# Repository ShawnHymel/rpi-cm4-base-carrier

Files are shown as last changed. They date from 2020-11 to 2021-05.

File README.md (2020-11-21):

# Raspberry Pi Compute Module 4 (CM4) Base Carrier

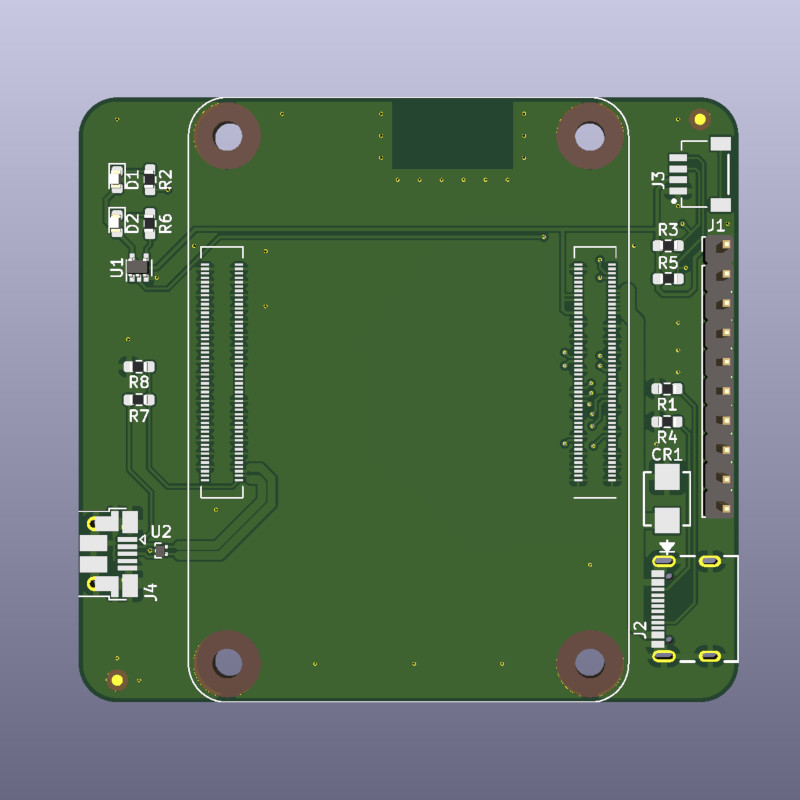
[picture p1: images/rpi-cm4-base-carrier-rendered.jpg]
Rendered example of RPi CM4 Carrier Template PCB


Simple carrier board for the Raspberry Pi Compute Module 4. It provides power to the module through the USB-C connector (power only, no data), USB client mode (host mode is not supported), Qwiic/Stemma connector for I2C lines, SPI, UART, and power/activity LEDs.

Feel free to modify this design for your own application. This PCB is not intended to be an end product but rather a demo to get people started making their own carrier boards for the CM4.

Note that USB traces were calculated for a 2-layer board with a 1.6mm height.

## License

Schematic and PCB layout files are licensed under the [CC BY 4.0](https://creativecommons.org/licenses/by/2.0/) license.

Individual components and footprints found in the CM4IO library are licensed as per the Design Files license found [here](https://datasheets.raspberrypi.org/license.html).

THE DESIGN IS PROVIDED "AS IS" AND THE AUTHOR DISCLAIMS ALL WARRANTIES WITH REGARD TO THIS DESIGN INCLUDING ALL IMPLIED WARRANTIES OF MERCHANTABILITY AND FITNESS. IN NO EVENT SHALL THE AUTHOR BE LIABLE FOR ANY SPECIAL, DIRECT, INDIRECT, OR CONSEQUENTIAL DAMAGES OR ANY DAMAGES WHATSOEVER RESULTING FROM LOSS OF USE, DATA OR PROFITS, WHETHER IN AN ACTION OF CONTRACT, NEGLIGENCE OR OTHER TORTIOUS ACTION, ARISING OUT OF OR IN CONNECTION WITH THE USE OR PERFORMANCE OF THIS DESIGN.

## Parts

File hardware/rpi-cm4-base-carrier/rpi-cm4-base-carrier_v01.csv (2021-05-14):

Reference | Quantity | Value | Footprint | Datasheet | Digi-Key_PN | MPN | Manufacturer | Part Description | AVAILABILITY | DESCRIPTION | MF | MP | PACKAGE | PRICE | STANDARD | Digi-Key_PN (Alt) | Field4 | Field5
CR1 | 1 | SMBJ5.0A-TR | footprints:SMBJ5.0A-TR |  | 497-3144-1-ND | SMBJ5.0A-TR | STMicroelectronics
D1 | 1 | LED Green | LED_SMD:LED_0603_1608Metric | ~ | 160-1478-1-ND | LTST-S270KGKT | Lite-On Inc. | Green 572nm LED Indication - Discrete 2.2V 2-SMD, No Lead
D2 | 1 | LED Red | LED_SMD:LED_0603_1608Metric | ~ | 160-1479-1-ND | LTST-S270KRKT | Lite-On Inc. | Red 620nm LED Indication - Discrete 2.2V 2-SMD, No Lead
J1 | 1 | DNP | Connector_PinHeader_2.54mm:PinHeader_1x10_P2.54mm_Vertical | ~
J2 | 1 | USB4105-GF-A | USB4105-GF-A:GCT_USB4105-GF-A |  | 2073-USB4105-GF-ACT-ND | USB4105-GF-A | GCT |  | Unavailable | USB - C _Type - C_ USB 2.0 Receptacle Connector 24 Position Surface Mount, Right Angle; Through Hole | Global Connector Technology | USB4105 | Package Analog Devices | None
J3 | 1 | SM04B-SRSS-TB(LF)(SN) | SM04B-SRSS-TB_LF__SN_:JST_SM04B-SRSS-TB(LF)(SN) |  | 455-1804-1-ND | SM04B-SRSS-TB(LF)(SN) | JST Sales America Inc. |  |  |  |  |  |  |  | Manufacturer recommendations
J4 | 1 | USB_OTG | CM4IO:USB_Micro-B_EDAC_UCON00686 | ~ | 609-4050-1-ND | 10103594-0001LF | Amphenol ICC (FCI)
JP1 | 1 | SolderJumper_2_Open | Jumper:SolderJumper-2_P1.3mm_Open_RoundedPad1.0x1.5mm | ~
Module1 | 1 | ComputeModule4-CM4 | CM4IO:Raspberry-Pi-4-Compute-Module |  | 2x H11615CT-ND | 2x DF40C-100DS-0.4V | Hirose |  |  |  |  |  |  |  |  | 2x H124602CT-ND | Hirose | 2x DF40C-100DS-0.4V
R1 R4 | 2 | 5.1k | Resistor_SMD:R_0603_1608Metric_Pad0.98x0.95mm_HandSolder | ~ | 311-5.10KHRCT-ND | RC0603FR-075K1L | Yageo
R2 R6 | 2 | 1k | Resistor_SMD:R_0603_1608Metric_Pad0.98x0.95mm_HandSolder | ~ | 311-1.00KHRCT-ND | RC0603FR-071KL | Yageo
R3 R5 | 2 | DNP | Resistor_SMD:R_0603_1608Metric_Pad0.98x0.95mm_HandSolder | ~
R7 R8 | 2 | 2.2K 1% | Resistor_SMD:R_0603_1608Metric_Pad0.98x0.95mm_HandSolder | ~ | 311-2.20KHRCT-ND | RC0603FR-072K2L | Yageo
U1 | 1 | 74LVC1G07SE-7 | Package_TO_SOT_SMD:SOT-353_SC-70-5 | http://www.ti.com/lit/sg/scyt129e/scyt129e.pdf | 74LVC1G07SE-7DICT-ND | 74LVC1G07SE-7 | Diodes Incorporated | Buffer, Non-Inverting 1 Element 1 Bit per Element Open Drain Output SOT-353
U2 | 1 | TPD2EUSB30 | Package_TO_SOT_SMD:Texas_DRT-3 | http://www.ti.com/lit/ds/symlink/tpd2eusb30a.pdf | 296-25509-1-ND | TPD2EUSB30DRTR | Texas Instruments

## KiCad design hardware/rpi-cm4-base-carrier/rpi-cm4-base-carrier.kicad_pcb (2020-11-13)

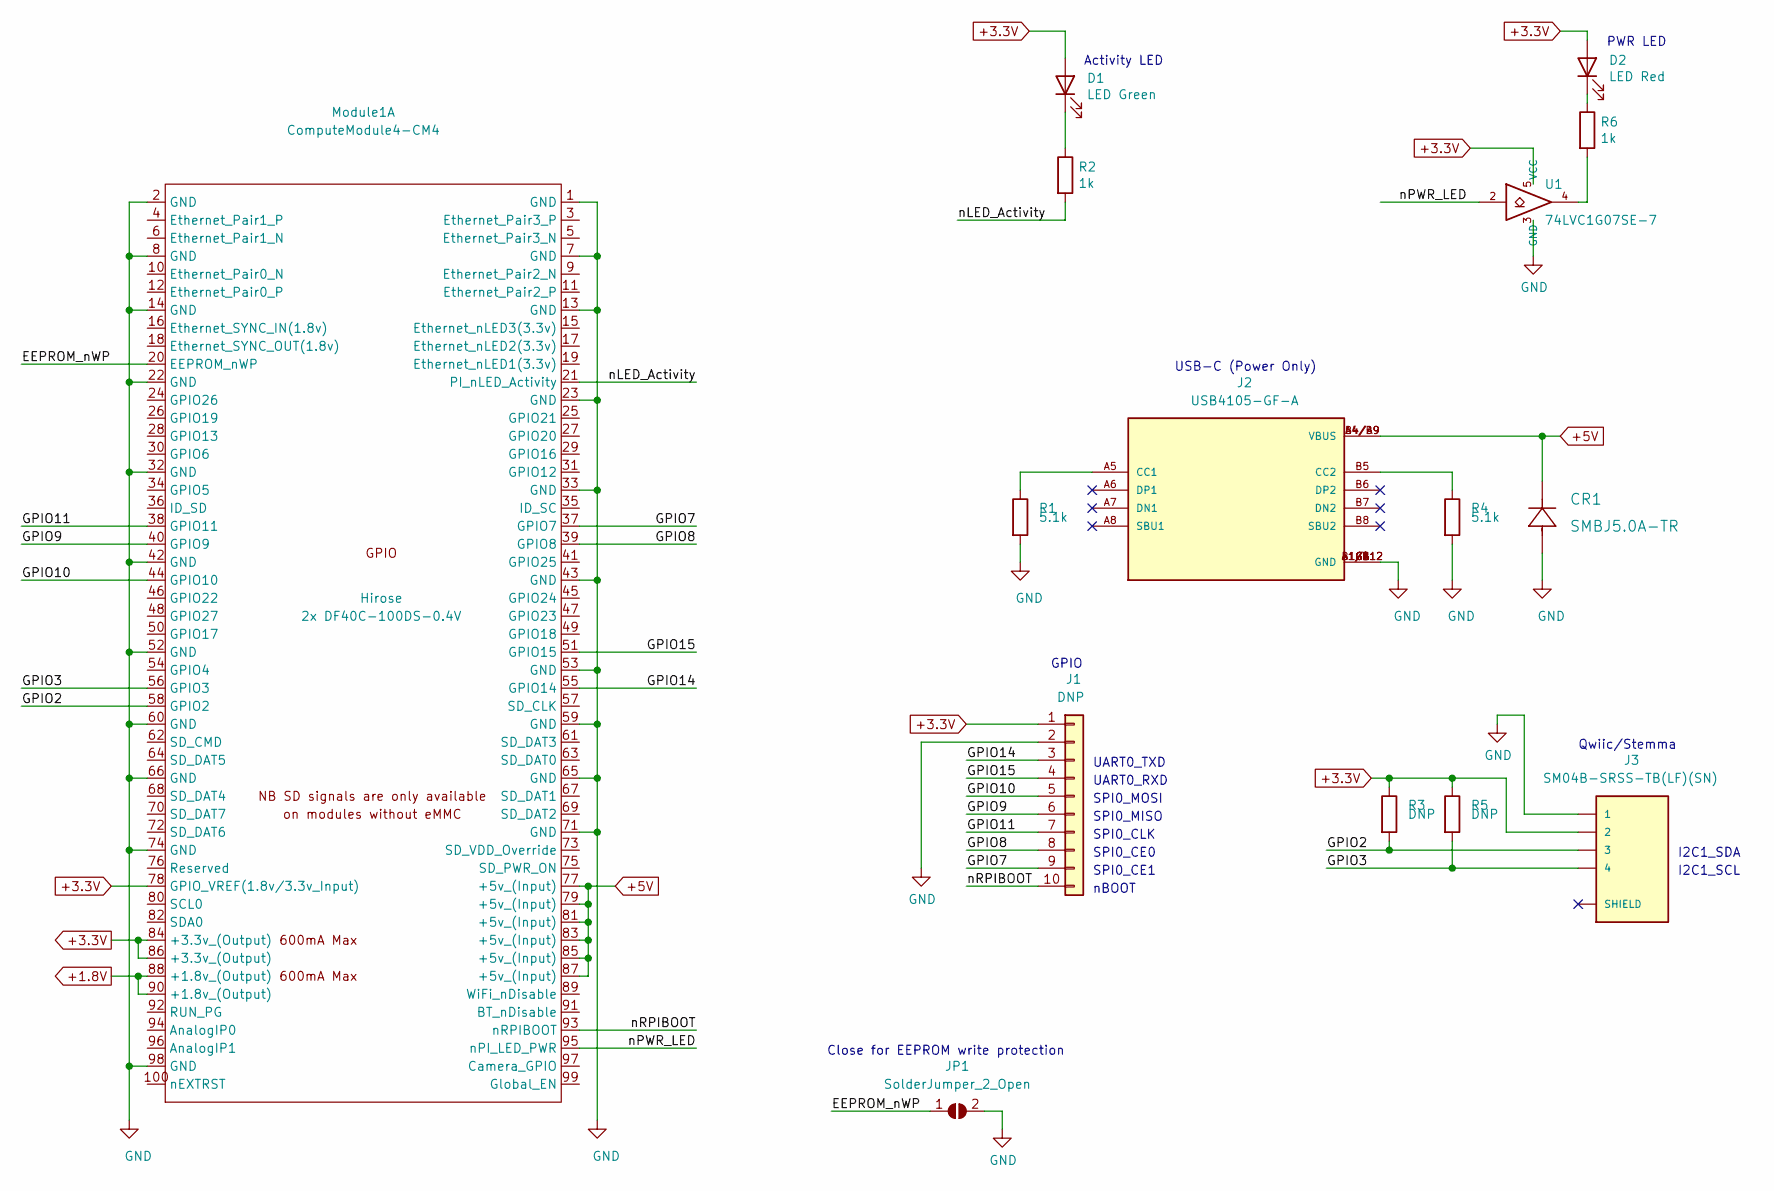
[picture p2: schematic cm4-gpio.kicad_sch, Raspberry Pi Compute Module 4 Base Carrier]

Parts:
CR1: SMBJ5.0A-TR; MPN SMBJ5.0A-TR; Digi-Key_PN 497-3144-1-ND
D1: LED Green; LED_0603_1608Metric; Part Description Green 572nm LED Indication - Discrete 2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; Digi-Key_PN 160-1478-1-ND
D2: LED Red; LED_0603_1608Metric; Part Description Red 620nm LED Indication - Discrete 2.2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; Digi-Key_PN 160-1479-1-ND
J1: DNP; PinHeader_1x10_P2.54mm_Vertical
J2: USB4105-GF-A; GCT_USB4105-GF-A; MPN USB4105-GF-A; Digi-Key_PN 2073-USB4105-GF-ACT-ND
J3: SM04B-SRSS-TB(LF)(SN); JST_SM04B-SRSS-TB(LF)(SN); MPN SM04B-SRSS-TB(LF)(SN); Digi-Key_PN 455-1804-1-ND
JP1: SolderJumper_2_Open; SolderJumper-2_P1.3mm_Open_RoundedPad1.0x1.5mm
Module1: ComputeModule4-CM4; Raspberry-Pi-4-Compute-Module; MPN 2x DF40C-100DS-0.4V; Digi-Key_PN 2x H11615CT-ND
R1, R4: 5.1k; R_0603_1608Metric_Pad0.98x0.95mm_HandSolder; MPN RC0603FR-075K1L; Digi-Key_PN 311-5.10KHRCT-ND
R2, R6: 1k; R_0603_1608Metric_Pad0.98x0.95mm_HandSolder; MPN RC0603FR-071KL; Digi-Key_PN 311-1.00KHRCT-ND
R3, R5: DNP; R_0603_1608Metric_Pad0.98x0.95mm_HandSolder
U1: 74LVC1G07SE-7; SOT-353_SC-70-5; Part Description Buffer, Non-Inverting 1 Element 1 Bit p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; Digi-Key_PN 74LVC1G07SE-7DICT-ND

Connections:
+1.8V: Module1.88 (+1.8v_(Output)), Module1.90 (+1.8v_(Output))
+3.3V: D1.2 (A), D2.2 (A), J1.1, J3.2, Module1.78 (GPIO_VREF(1.8v/3.3v_Input)), Module1.84 (+3.3v_(Output)), Module1.86 (+3.3v_(Output)), R3.1, R5.1, U1.5 (VCC)
+5V: CR1.1, J2.A4/B9 (VBUS), J2.B4/A9 (VBUS), Module1.77 (+5v_(Input)), Module1.79 (+5v_(Input)), Module1.81 (+5v_(Input)), Module1.83 (+5v_(Input)), Module1.85 (+5v_(Input)), Module1.87 (+5v_(Input))
/CM4 GPIO/EEPROM_nWP: JP1.1 (A), Module1.20 (EEPROM_nWP)
/CM4 GPIO/GPIO2: J3.3, Module1.58 (GPIO2), R3.2
/CM4 GPIO/GPIO3: J3.4, Module1.56 (GPIO3), R5.2
/CM4 GPIO/GPIO7: J1.9, Module1.37 (GPIO7)
/CM4 GPIO/GPIO8: J1.8, Module1.39 (GPIO8)
/CM4 GPIO/GPIO9: J1.6, Module1.40 (GPIO9)
/CM4 GPIO/GPIO10: J1.5, Module1.44 (GPIO10)
/CM4 GPIO/GPIO11: J1.7, Module1.38 (GPIO11)
/CM4 GPIO/GPIO14: J1.3, Module1.55 (GPIO14)
/CM4 GPIO/GPIO15: J1.4, Module1.51 (GPIO15)
/CM4 GPIO/nLED_Activity: Module1.21 (PI_nLED_Activity), R2.2
/CM4 GPIO/nPWR_LED: Module1.95 (nPI_LED_PWR), U1.2
/CM4 GPIO/nRPIBOOT: J1.10, Module1.93 (nRPIBOOT)
GND: CR1.2, J1.2, J2.A1/B12 (GND), J2.B1/A12 (GND), J2.G1 (GND), J2.G2 (GND), J2.G3 (GND), J2.G4 (GND), J3.1, JP1.2 (B), Module1.1 (GND), Module1.2 (GND), Module1.7 (GND), Module1.8 (GND), Module1.13 (GND), Module1.14 (GND), Module1.22 (GND), Module1.23 (GND), Module1.32 (GND), Module1.33 (GND), Module1.42 (GND), Module1.43 (GND), Module1.52 (GND), Module1.53 (GND), Module1.59 (GND), Module1.60 (GND), Module1.65 (GND), Module1.66 (GND), Module1.71 (GND), Module1.74 (GND), Module1.98 (GND), R1.2, R4.2, U1.3 (GND); also elsewhere on the board
unnamed: D1.1 (K), R2.1
unnamed: D2.1 (K), R6.1
unnamed: J2.A5 (CC1), R1.1
unnamed: J2.B5 (CC2), R4.1
unnamed: J3.S1 (SHIELD), J3.S2 (SHIELD)
unnamed: R6.2, U1.4

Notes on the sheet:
Close for EEPROM write protection
Activity LED
GPIO
UART0_TXD
UART0_RXD
SPI0_MOSI
SPI0_MISO
SPI0_CLK
SPI0_CE0
SPI0_CE1
nBOOT
USB-C (Power Only)
PWR LED
Qwiic/Stemma
I2C1_SDA
I2C1_SCL

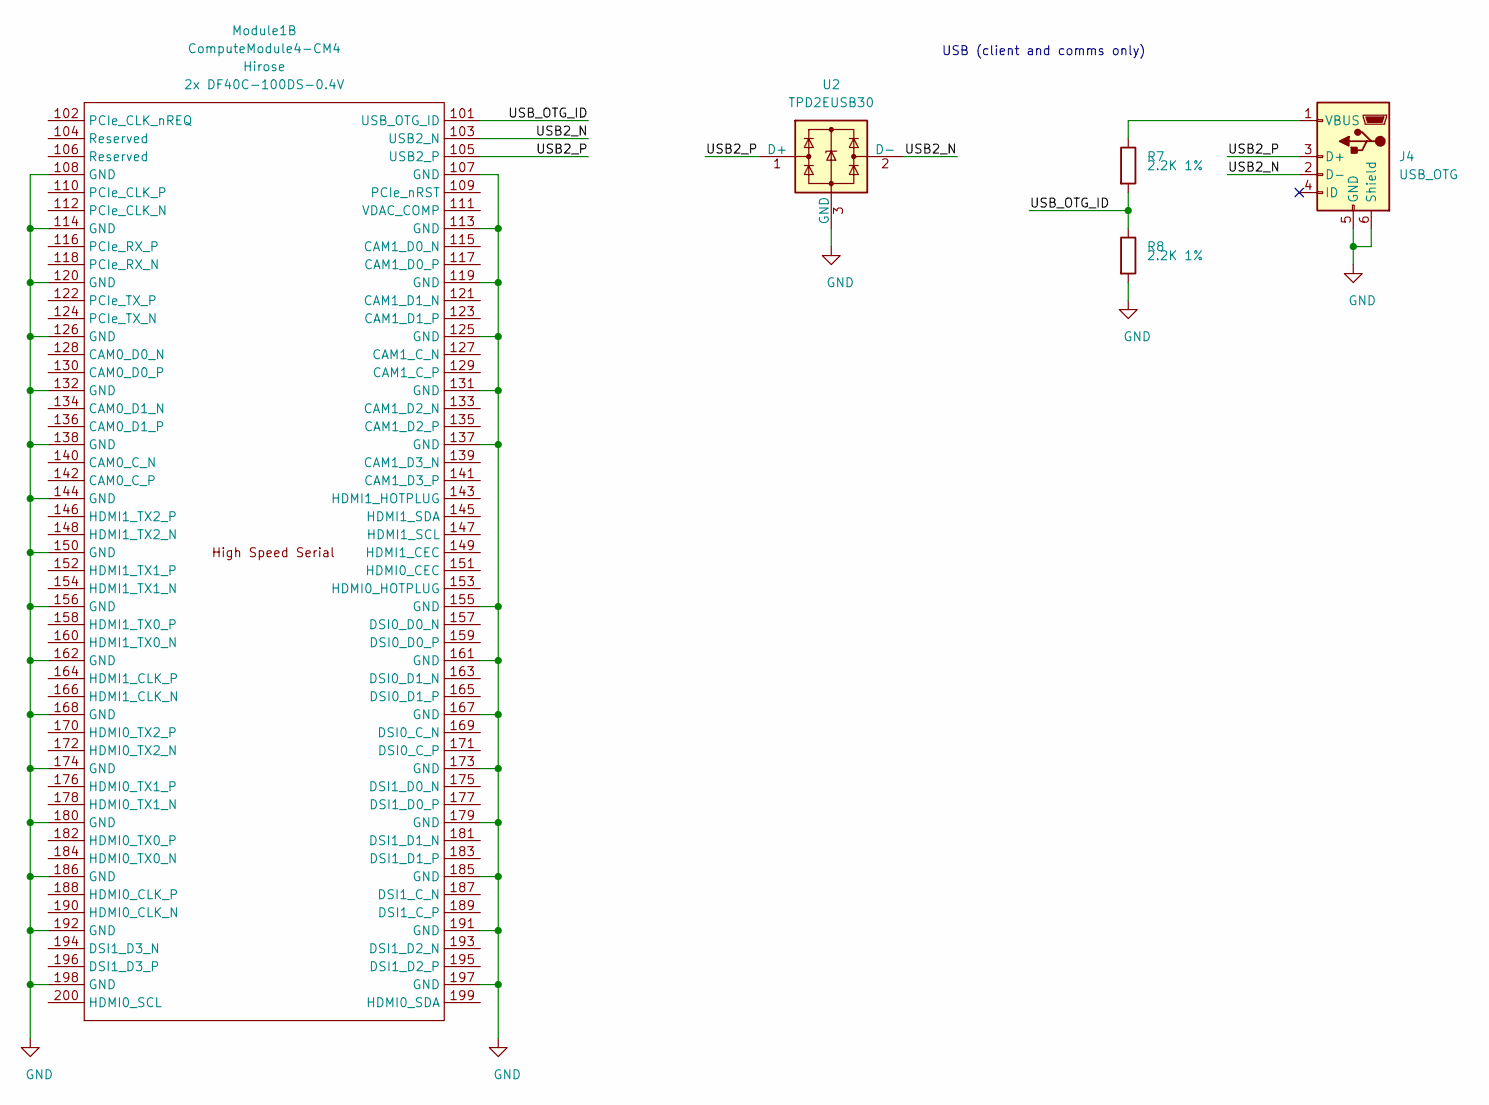
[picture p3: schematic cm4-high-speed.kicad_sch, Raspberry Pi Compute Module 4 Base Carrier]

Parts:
J4: USB_OTG; USB_Micro-B_EDAC_UCON00686; MPN 10103594-0001LF; Digi-Key_PN 609-4050-1-ND
Module1: ComputeModule4-CM4; Raspberry-Pi-4-Compute-Module; Digi-Key_PN 2x H11615CT-ND
R7, R8: 2.2K 1%; R_0603_1608Metric_Pad0.98x0.95mm_HandSolder; MPN RC0603FR-072K2L; Digi-Key_PN 311-2.20KHRCT-ND
U2: TPD2EUSB30; Texas_DRT-3; MPN TPD2EUSB30DRTR; Digi-Key_PN 296-25509-1-ND

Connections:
/CM4 High Speed/USB2_N: J4.2 (D-), Module1.103 (USB2_N), U2.2 (D-)
/CM4 High Speed/USB2_P: J4.3 (D+), Module1.105 (USB2_P), U2.1 (D+)
/CM4 High Speed/USB_OTG_ID: Module1.101 (USB_OTG_ID), R7.2, R8.1
GND: J4.5 (GND), J4.6 (Shield), Module1.107 (GND), Module1.108 (GND), Module1.113 (GND), Module1.114 (GND), Module1.119 (GND), Module1.120 (GND), Module1.125 (GND), Module1.126 (GND), Module1.131 (GND), Module1.132 (GND), Module1.137 (GND), Module1.138 (GND), Module1.144 (GND), Module1.150 (GND), Module1.155 (GND), Module1.156 (GND), Module1.161 (GND), Module1.162 (GND), Module1.167 (GND), Module1.168 (GND), Module1.173 (GND), Module1.174 (GND), Module1.179 (GND), Module1.180 (GND), Module1.185 (GND), Module1.186 (GND), Module1.191 (GND), Module1.192 (GND), Module1.197 (GND), Module1.198 (GND), R8.2, U2.3 (GND); also elsewhere on the board
unnamed: J4.1 (VBUS), R7.1

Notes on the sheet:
USB (client and comms only)

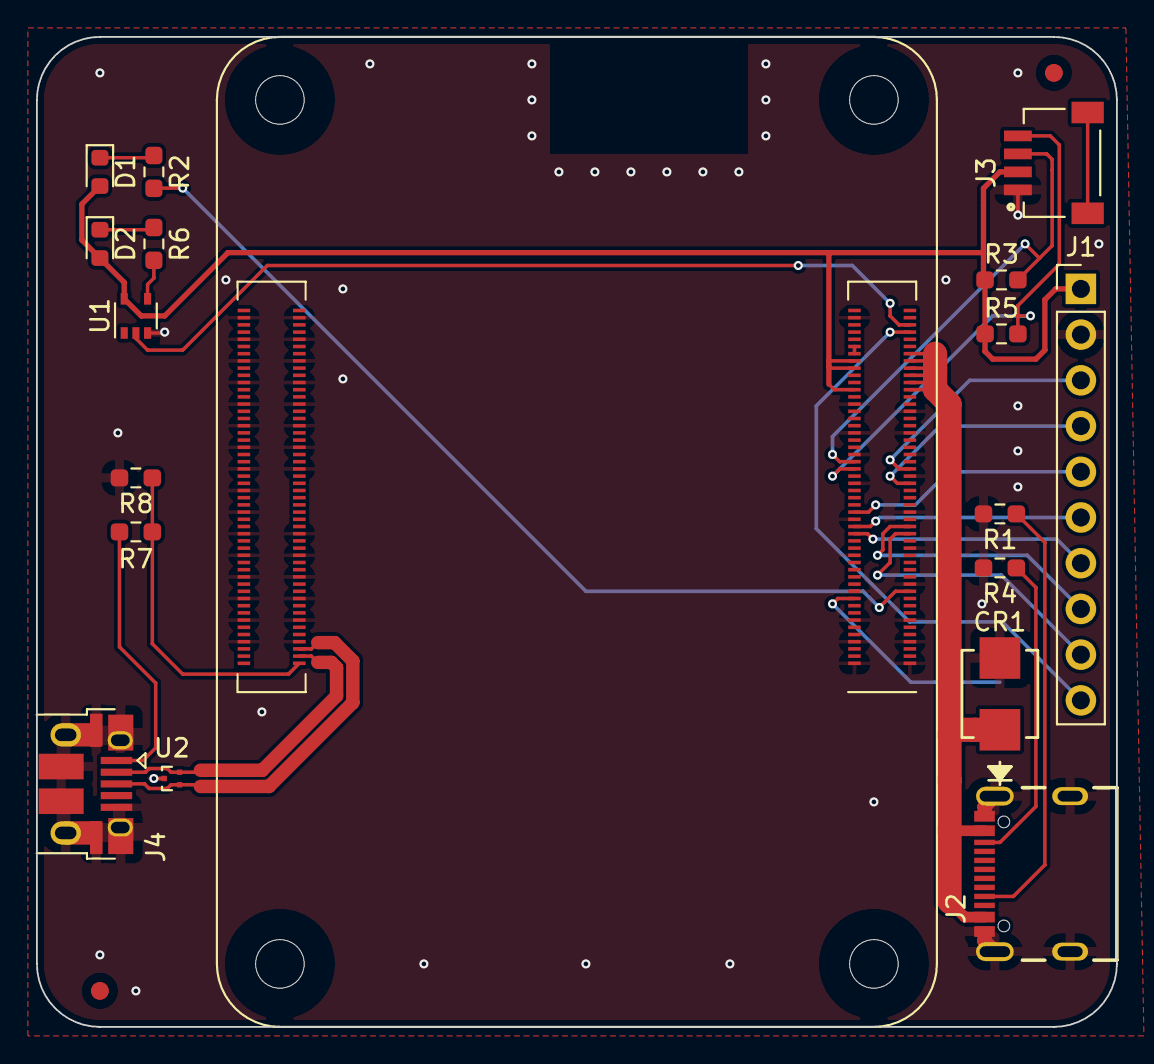
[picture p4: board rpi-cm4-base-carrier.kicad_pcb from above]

Board: 2 copper layers, 60.0 x 55.0 mm, 19 parts (1 on the bottom side), 27 nets.

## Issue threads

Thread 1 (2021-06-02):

What is the pin layout for J1 ?

markbirss, 2021-06-02:
Kindly share more details for J1 pin layout

markbirss, 2021-06-02:
OK, sorry  i see it is here
https://www.digikey.com/maker-media/08979e6a-76ae-4db2-9c90-d11a8b6fd896

https://www.digikey.com/en/maker/projects/creating-a-raspberry-pi-compute-module-4-cm4-carrier-board-in-kicad/7812da347e5e409aa28d59ea2aaea490

Closed 2021-06-02.

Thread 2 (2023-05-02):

USB device connections?

nettlep, 2023-05-02:
I'd like to support plugging in a USB microphone.

Can I use the Micro-USB connector for this? I'm hoping that I can use this connector for a dual purpose. Uploading the OS (with the nRPIBOOT jumper closed) or as a USB port (with the jumper open).

Is this possible or would I need to include a USB host controller like the one in the reference CM4IO board?

Closed 2023-05-03.

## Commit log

2020-11-06 Added USB connectors
    [cm4-gpio.kicad_sch, cm4-high-speed.kicad_sch, rpi-cm4-base-carrier.kicad_pcb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]
2020-11-07 Finished schematic
    [cm4-gpio.kicad_sch, cm4-high-speed.kicad_sch, rpi-cm4-base-carrier.kicad_pcb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]
2020-11-07 Added labels to schematic sections
    [cm4-gpio.kicad_sch, cm4-high-speed.kicad_sch]
2020-11-09 Placed components
    [cm4-gpio.kicad_sch, cm4-high-speed.kicad_sch, rpi-cm4-base-carrier.kicad_pcb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]
2020-11-12 Pretended to route USB lines
    [cm4-gpio.kicad_sch, rpi-cm4-base-carrier.kicad_pcb]
2020-11-13 Finished with PCB layout
    [rpi-cm4-base-carrier-B_Cu.gbl, rpi-cm4-base-carrier-B_Mask.gbs, rpi-cm4-base-carrier-B_Paste.gbp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]
2021-05-14 Added BOM
    [rpi-cm4-base-carrier_v01.csv]

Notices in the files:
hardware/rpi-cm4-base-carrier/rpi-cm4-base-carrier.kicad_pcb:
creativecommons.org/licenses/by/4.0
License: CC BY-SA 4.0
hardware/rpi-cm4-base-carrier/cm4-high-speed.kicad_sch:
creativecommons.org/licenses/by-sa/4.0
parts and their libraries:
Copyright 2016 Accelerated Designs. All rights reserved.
